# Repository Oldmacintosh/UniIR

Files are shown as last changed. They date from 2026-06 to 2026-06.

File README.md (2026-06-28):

# UniIr — ESP32 Universal Remote

A DIY **universal remote**. An ESP32 captures IR commands from any
remote, stores a command library, and replays them over Bluetooth on request —
and it can run **activity-based automation** on its own: turn your gear on when
there's activity in the room and off again after a period of quiet.

It ships as three parts:

- **Firmware** for the ESP32 (`UniIR.ino`).
- **`UniIr`** — a small Python library that controls the device over its
  Bluetooth/USB serial link (`__init__.py`).
- **A demo GUI** (`demo.py`) that uses the library — capture, replay, organise a
  command library, and configure automation.

It also includes a parametric **3D-printable enclosure** (`UniIR.scad`).

---

## Screenshots

### Circuit / wiring diagram
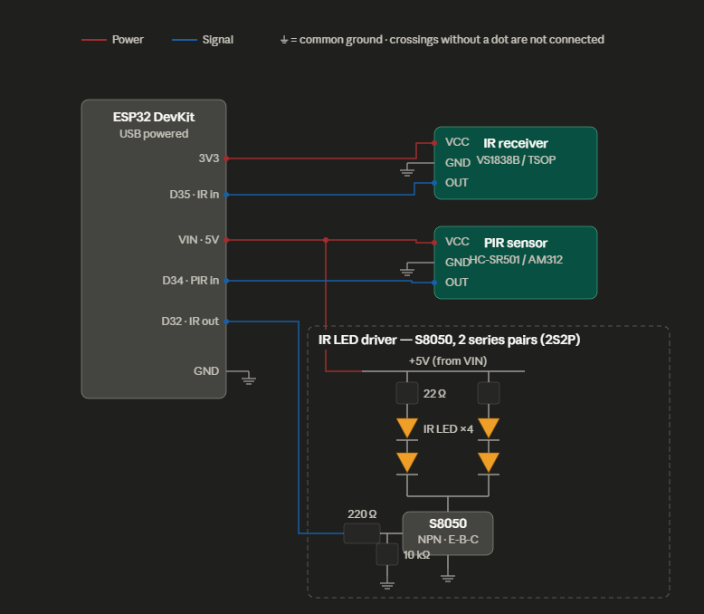
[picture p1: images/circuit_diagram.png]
Circuit diagram


### 3D-printed enclosure
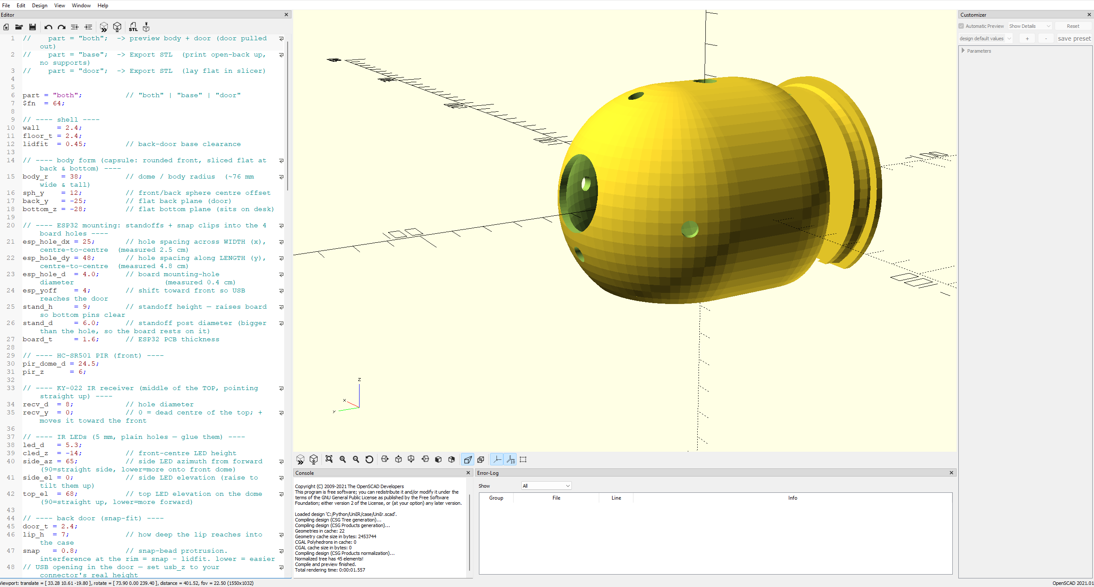
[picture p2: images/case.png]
3D-printed case


### Demo GUI
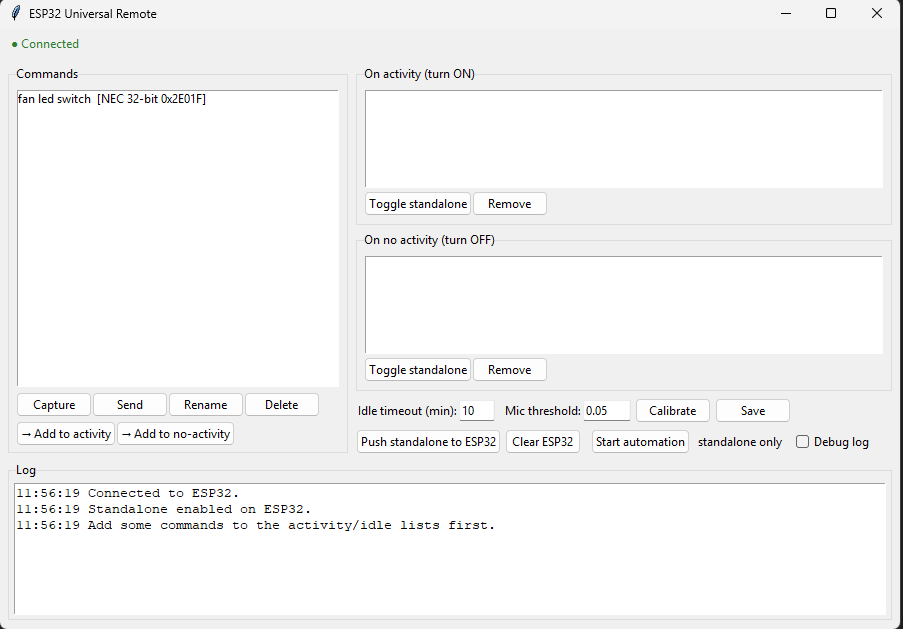
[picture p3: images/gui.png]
Demo GUI


## Table of contents

1. [What it does](#what-it-does)
2. [Project structure](#project-structure)
3. [Hardware](#hardware)
4. [The IR LED driver](#the-ir-led-driver)
5. [3D-printed case](#3d-printed-case)
6. [Firmware](#firmware)
7. [The `UniIr` library](#the-uniir-library)
8. [The demo GUI](#the-demo-gui)
9. [How automation works](#how-automation-works)
10. [macOS Bluetooth notes & troubleshooting](#macos-bluetooth-notes--troubleshooting)
11. [Serial protocol reference](#serial-protocol-reference)

---

## What it does

- **Capture** IR commands from any remote — ordinary remotes (NEC, Sony, RC5,
  etc.), **stateful air-conditioner** remotes (the whole state frame is captured
  and replayed verbatim, so there's no model-lockup risk), and unknown signals
  as **raw** timing.
- **Replay** any stored command on demand.
- **Activity automation** — fuse keyboard, mouse, microphone loudness and a PIR
  motion sensor into a single "active / idle" signal. When activity resumes it
  fires your *on* commands; after a configurable idle timeout it fires your *off*
  commands.
- **Standalone mode** — the ESP32 stores a copy of the automation and keeps
  running it even when the PC is asleep or the app is closed.
- **Self-healing connection** — the library auto-reconnects, verifies the link
  with a handshake, and survives the device resetting (handled carefully because
  macOS Bluetooth serial is fussy about stale links).

---

## Project structure

```
UniIr/
├── __init__.py            # the UniIr library (device client + automation runner)
├── demo.py                # tkinter demo GUI built on the library
├── UniIR.ino              # ESP32 firmware (Arduino)
├── case/                  # parametric enclosure (OpenSCAD)
├── images/                
└── README.md
```

---

## Hardware

### Bill of materials

| Qty | Part | Notes |
|----:|---|---|
| 1 | ESP32 DevKit (30-pin DOIT / WROOM-32) | has built-in Classic Bluetooth |
| 1 | KY-022 IR receiver module | the "eye" that captures remotes |
| 1 | HC-SR501 PIR motion sensor | the big white dome |
| 1 | S8050 NPN transistor | switches the IR LEDs (TO-92) |
| 4 | IR LED, 940 nm, 5 mm | the IR "blasters" |
| 2 | 22 Ω resistor, ¼ W | one per LED branch |
| 1 | 220 Ω resistor, ¼ W | transistor base |
| 1 | 10 kΩ resistor, ¼ W | base pull-down |
| 1 | USB cable + 5 V supply | powers everything |
| — | jumper wires, 3D-printed case | — |

### Pin connections

| ESP32 pin | Connects to | Purpose |
|---|---|---|
| **GPIO35** (D35) | KY-022 **S** (signal out) | IR receive (input-only pin) |
| **GPIO34** (D34) | HC-SR501 **OUT** | PIR motion (input-only pin) |
| **GPIO32** (D32) | 220 Ω → S8050 **base** | IR transmit |
| **3V3** | KY-022 **+ (VCC)** | receiver power |
| **VIN (5V)** | HC-SR501 **VCC**, LED driver **+** | from USB |
| **GND** | all GND, S8050 **emitter**, 10 kΩ | common ground |

> GPIO34 and GPIO35 are **input-only** pins — perfect for the two sensors, and
> they can't accidentally be driven as outputs.

Everything is powered from the ESP32's USB connector; the 5 V for the PIR and the
LED array is taken from the **VIN** pin.

---

## The IR LED driver

A GPIO pin can only source a few milliamps — nowhere near enough to drive IR LEDs
to useful range. So the four LEDs are driven by an **S8050 transistor** in a
**2S2P** arrangement (two parallel branches, each two LEDs in series):

```
              +5V (VIN)
                │
        ┌───────┴───────┐
       22Ω             22Ω
        │               │
       LED             LED
        │               │
       LED             LED
        │               │
        └───────┬───────┘
                │ (collector)
            [ S8050 ]  ── base ── 220Ω ── GPIO32
                │ (emitter)        │
               GND              10kΩ → GND
```

- Each 22 Ω resistor sets ~85–100 mA per branch (~200 mA total).
- The 220 Ω feeds the base; the 10 kΩ holds the transistor off at boot.
- **S8050 pinout is E–B–C** (emitter, base, collector) with the flat face toward
  you — note it's the *reverse* of a BC547.

The firmware only pulses the LEDs during a transmit burst, so the resistors stay
cool. This is the difference between "works only if you aim it" and blasting IR
across a room.

---

## 3D-printed case

`UniIR.scad` is a **parametric** enclosure: a domed front, a flat removable
**snap-fit back door**, and a flat bottom so it sits on a desk. All the four IR
LEDs poke out of the dome (front-centre, left, right and top) for wide coverage,
the PIR dome sits on the front, and the IR receiver looks out the **top centre**.
The ESP32 clips onto four standoffs through its mounting holes.

### Printing it

1. Install [OpenSCAD](https://openscad.org).
2. Open `UniIR.scad`. Every dimension is a variable at the top — set them
   to match your parts (board size, mounting-hole spacing/diameter, etc.).
3. Set `part = "base";`, press **F6** (render), then **File → Export → STL**.
4. Set `part = "door";`, render again, export the door.
5. Slice and print — body open-side up, door laid flat. No supports needed.

Or from the command line:

```bash
openscad -o base.stl -D 'part="base"' ir_hub_case.scad
openscad -o door.stl -D 'part="door"' ir_hub_case.scad
```

**Tunable parameters worth checking first:** `esp_hole_dx` / `esp_hole_dy` /
`esp_hole_d` (your board's mounting holes), `stand_h` (standoff height — must
clear your bottom pins/connectors), `usb_z` (USB connector height), and `snap`
(back-door snap tightness). Set the HC-SR501's two trim pots **before** closing
the case — they end up facing inward.

---

## Firmware

### Toolchain

- [Arduino IDE](https://www.arduino.cc/en/software) with the **ESP32 board
  package** installed (Boards Manager → "esp32" by Espressif).
- Library: **IRremoteESP8266** (Library Manager).
- `BluetoothSerial` ships with the ESP32 core.

### Flashing

1. Open `UniIr.ino` in the Arduino IDE.
2. Select your board (e.g. "DOIT ESP32 DEVKIT V1") and the right serial port.
3. Upload. Open the Serial Monitor at **115200** to watch debug output.

The ESP32 advertises over Bluetooth as **`uniir`**. Pair it from your computer's
Bluetooth settings. On macOS it then appears as the serial device
**`/dev/cu.uniir`**; on Windows it's assigned a COM port.

---

## The `UniIr` library

### Install

```bash
pip install pyserial                       # required
pip install pynput sounddevice numpy       # only needed to RUN automation
```

### Quick start

```python
from UniIr import UniIr            # the device client class

remote = UniIr("/dev/cu.uniir",       # or "COM$" on Windows
            on_status=lambda up: print("connected" if up else "disconnected"),
            on_log=print)

# Capture a button — press the remote when your own UI prompts the user
cmd = remote.capture()                # -> a command dict, or None on timeout
if cmd:
    remote.send(cmd)                  # replay it (blocks until the ESP32 confirms)

# Stream motion events
remote.pir_handler = lambda line: print("motion!" if line == "PIR 1" else "still")

remote.close()
```

The connection is **managed for you**: constructing `UniIr(...)` starts
background threads that open the port, verify it with a handshake, watch a
heartbeat, and reconnect automatically. `remote.connected` is `True` only after a
verified link.

### API reference

**`UniIr(port, baud=115200, on_status=None, on_log=None, auto_connect=True)`**

| Method | Description |
|---|---|
| `capture(timeout=25)` | Capture the next IR signal → command dict or `None` |
| `send(cmd)` | Replay a command, blocking until confirmed → `bool` |
| `send_async(cmd)` | Fire a code/state command without waiting (for automation) |
| `provision(activity_specs, idle_specs, timeout_sec)` | Store standalone automation on the ESP32 → `(ok, where)` |
| `set_standalone(enabled)` | Turn the ESP32's standalone mode on/off |
| `clear_standalone()` | Erase standalone commands from the ESP32 |
| `ping(timeout=3)` | `True` if the device answers |
| `close()` | Stop threads and release the port |

| Attribute | Description |
|---|---|
| `connected` | `True` after a verified handshake |
| `pir_handler` | Set to `f(line)` to receive `"PIR 1"` / `"PIR 0"` motion lines |
| `on_status`, `on_log` | Callbacks (also settable in the constructor) |

### Command data model

A command is a plain `dict`, one of three shapes:

```python
{"type": "code",  "proto": 3, "name": "TV_power", "bits": 32, "value": "20df10ef"}
{"type": "state", "proto": 18, "name": "AC_cool", "nbytes": 3, "bytes": ["a1","b2","c3"]}
{"type": "raw",   "name": "RAW", "data": [9000, 4500, 560, 560, ...]}
```

Helper functions: `describe(cmd)` (human-readable string), `to_spec(cmd)`
(encode for the ESP32; raises for raw), `is_storable(cmd)` (can it run
standalone?).

### Storage helpers

```python
from UniIr import load_data, save_data

data = load_data()                 # -> {"commands": {...}, "automation": {...}}
data["commands"]["tv_power"] = cmd
save_data(data)                    # writes commands.json
```

### Command-line connectivity test

```bash
python -m UniIr            # if installed as a package
# or, from inside the folder:
python __init__.py --port /dev/cu.uniir
```

---

## The demo GUI

`demo.py` is a tkinter app that exercises the whole library. Run it:

```bash
python -m UniIr.demo                 # from the parent folder (recommended)
# or, from inside the UniIr folder:
python demo.py --port /dev/cu.uniir
```

On macOS the default port is `/dev/cu.uniir`, so you can usually omit `--port`.

### What it does

- **Command library** — capture, send, rename and delete IR commands; everything
  is saved to `commands.json`.
- **Automation lists** — add commands to an **On activity** list (fired when
  activity resumes) and an **On no activity** list (fired after the idle
  timeout). Mark commands "standalone" to also store them on the ESP32.
- **Settings** — idle timeout (minutes), microphone threshold, and a
  **Calibrate** button that measures ambient noise and sets a sensible threshold.
- **Push standalone to ESP32 / Clear ESP32** — provision or wipe the device's
  own copy of the automation.
- **Start / Stop automation** and a **Debug log** toggle (see below).
- **Connection status** — a live ● Connected / ● Disconnected indicator and a
  timestamped log.

### macOS permissions

To *run* automation, the OS must allow the Python process to watch input and the
mic:

- **System Settings → Privacy & Security → Microphone** → allow Python/Terminal.
- **System Settings → Privacy & Security → Input Monitoring** → allow
  Python/Terminal.

---

## How automation works

The idea is simple: **activity = devices on, sustained quiet = devices off.**

- The PC runner fuses four signals — **keyboard**, **mouse**, **microphone
  loudness**, and **PIR motion** from the ESP32. Any of them counts as activity.
- When automation starts it **assumes the devices are already on** and begins the
  idle countdown immediately.
- When activity resumes after being idle, it fires the **On activity** commands.
- After `timeout` seconds with no activity from any source, it fires the **On no
  activity** commands.

### Persisted on/off state

Automation has a single saved intent (`enabled` in `commands.json`):

- **First ever launch** → on by default; it starts as soon as the device
  connects.
- After that, the stored state is used and **synced to the ESP32** on every
  connect.
- **Disconnecting stops automation** (it needs the device), and it can only be
  enabled while connected. On reconnect it resumes to the stored state.

### Standalone mode

If you "push standalone to ESP32", the device keeps a copy of your *activity* and
*idle* command lists plus the timeout. When the PC's heartbeat stops (app closed,
laptop asleep), the ESP32 takes over using the PIR sensor alone — so the room
automation keeps working with the computer off.

### Debug mode

Tick **Debug log** to see exactly what's keeping the system awake — useful for
tuning the timeout. With it on, the log shows (tagged `[debug]`):

- `timer reset by keyboard / mouse / sound / motion` every time activity restarts
  the countdown (high-rate sources throttled so they don't flood the log),
- `quiet for Ns — off in Ms` every few seconds while devices are on,
- each command fired, by name, and PIR clear events.

If your gear keeps staying on, debug usually reveals the mic threshold is too low
(catching background noise) or the PIR is re-triggering.

---

## macOS Bluetooth notes & troubleshooting

macOS Bluetooth serial (SPP) is more finicky than Windows. The firmware and
library work around the common issues:

- **"Connected" but nothing happens.** macOS can open a stale port that carries
  no data. The library only reports *Connected* after a **PING/PONG handshake**,
  so a dead link shows as Disconnected and keeps retrying.
- **Won't reconnect after the ESP32 resets without re-pairing.** macOS often
  doesn't tear down the old session. The firmware now **drops its Bluetooth
  client** when the PC's heartbeat stops (~12 s), forcing a fresh session so the
  app reconnects on its own — no re-pair needed.
- **Reconnect detection.** The ESP32 answers each heartbeat with `HBOK`; if the
  library hears nothing for 12 s it declares the link dead and reconnects.

If it still won't reconnect, remove "uniir" in **Bluetooth settings** and pair it
again. On Windows none of this applies — just pass the right `--port COMx`.

---

## Serial protocol reference

All lines are newline-terminated ASCII at 115200 baud.

| Direction | Line | Meaning |
|---|---|---|
| → | `PING` / `HB` | liveness probe / heartbeat |
| ← | `PONG` / `HBOK` | replies |
| → | `CAP` | capture the next IR signal |
| ← | `CODE <proto> <name> <bits> <hex>` | captured a normal remote |
| ← | `STATE <proto> <name> <nbytes> <bytes…>` | captured a stateful (AC) remote |
| ← | `RAW <len> <µs…>` | captured an unknown signal |
| → | `SEND CODE …` / `SEND STATE …` | replay a command |
| → | `LOADRAW <n>` → `D <values…>` → `FIRE` | replay a raw command |
| → | `AUTOCFG <sec>` / `AUTOACT <spec>` / `AUTOIDLE <spec>` / `AUTOSAVE` | provision standalone |
| → | `AUTOEN 1\|0` / `AUTOCLEAR` | enable/disable / wipe standalone |
| ← | `PIR 1` / `PIR 0` | async motion start / stop |
| ← | `ACK` / `SENT` / `TIMEOUT` | acknowledgements |

---

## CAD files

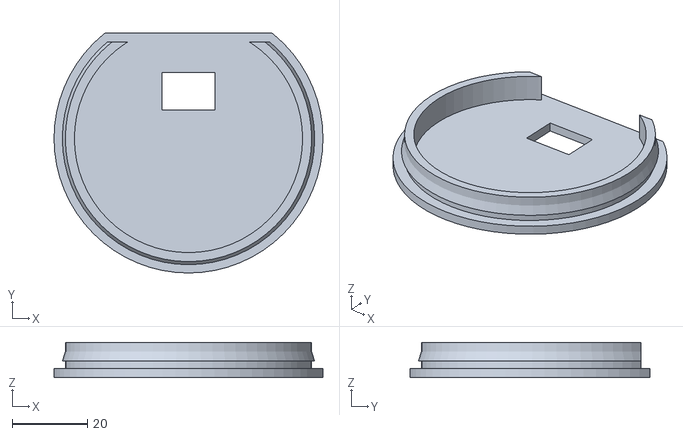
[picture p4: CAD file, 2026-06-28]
case/door.stl
71.4 x 63.7 x 9.40

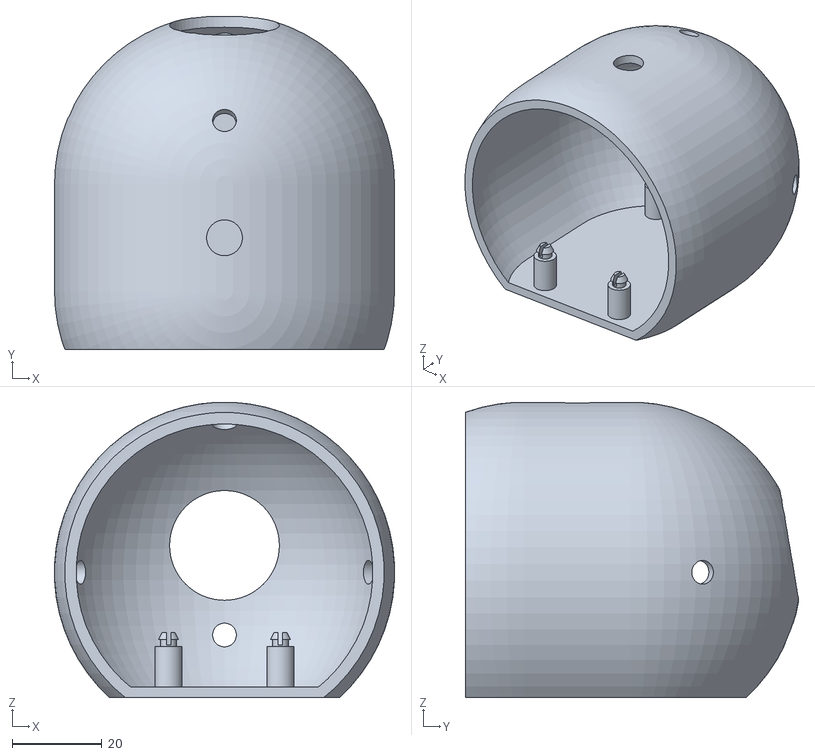
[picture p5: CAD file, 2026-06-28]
case/base.stl
75.9 x 74.5 x 66.0

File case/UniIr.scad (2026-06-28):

//    part = "both";  -> preview body + door (door pulled out)
//    part = "base";  -> Export STL  (print open-back up, no supports)
//    part = "door";  -> Export STL  (lay flat in slicer)


part = "both";          // "both" | "base" | "door"
$fn  = 64;

// ---- shell ----
wall    = 2.4;
floor_t = 2.4;
lidfit  = 0.45;         // back-door base clearance

// ---- body form (capsule: rounded front, sliced flat at back & bottom) ----
body_r   = 38;          // dome / body radius  (~76 mm wide & tall)
sph_y    = 12;          // front/back sphere centre offset
back_y   = -25;         // flat back plane (door)
bottom_z = -28;         // flat bottom plane (sits on desk)

// ---- ESP32 mounting: standoffs + snap clips into the 4 board holes ----
esp_hole_dx = 25;       // hole spacing across WIDTH (x), centre-to-centre  (measured 2.5 cm)
esp_hole_dy = 48;       // hole spacing along LENGTH (y), centre-to-centre  (measured 4.8 cm)
esp_hole_d  = 4.0;      // board mounting-hole diameter                     (measured 0.4 cm)
esp_yoff    = 4;        // shift toward front so USB reaches the door
stand_h     = 9;        // standoff height — raises board so bottom pins clear
stand_d     = 6.0;      // standoff post diameter (bigger than the hole, so the board rests on it)
board_t     = 1.6;      // ESP32 PCB thickness

// ---- HC-SR501 PIR (front) ----
pir_dome_d = 24.5;
pir_z      = 6;

// ---- KY-022 IR receiver (middle of the TOP, pointing straight up) ----
recv_d  = 8;            // hole diameter
recv_y  = 0;            // 0 = dead centre of the top; + moves it toward the front

// ---- IR LEDs (5 mm, plain holes — glue them) ----
led_d   = 5.3;
cled_z  = -14;          // front-centre LED height
side_az = 65;           // side LED azimuth from forward (90=straight side, lower=more onto front dome)
side_el = 0;            // side LED elevation (raise to tilt them up)
top_el  = 68;           // top LED elevation on the dome (90=straight up, lower=more forward)

// ---- back door (snap-fit) ----
door_t = 2.4;
lip_h  = 7;             // how deep the lip reaches into the case
snap   = 0.8;           // snap-bead protrusion. interference at the rim = snap - lidfit. lower = easier
// USB opening in the door — set usb_z to your connector's real height
usb_w  = 14;
usb_h  = 10;
usb_z  = -12.5;         // centre height of the USB connector (board is raised on the standoffs)

// ---- derived ----
back_cy = -sph_y;
r_back  = sqrt(body_r*body_r - (back_y-back_cy)*(back_y-back_cy));
r_in    = sqrt((body_r-wall)*(body_r-wall) - (back_y-back_cy)*(back_y-back_cy));
floor_z = bottom_z + floor_t;

// =====================================================================
//  helpers
// =====================================================================
// a +Y hole (the part faces outward along +Y); place at desired x/z
module led_y(dd) { translate([0,-5,0]) rotate([-90,0,0]) cylinder(h=70, d=dd); }

// place a child (modelled along +Y outward) on the FRONT dome surface
module place_dome(el, az) {
    translate([0, sph_y, 0]) rotate([0,0,az]) rotate([el,0,0])
        translate([0, body_r, 0]) children();
}

// snap-clip post: standoff + split peg + barb that clicks into a board hole
module clip_post() {
    peg_d  = esp_hole_d - 0.4;     // peg passes through the hole
    barb_d = esp_hole_d + 0.5;     // smaller barb so it snaps in easily (was +1.0)
    cylinder(d=stand_d, h=stand_h);                       // standoff (board rests on top)
    difference() {
        union() {
            translate([0,0,stand_h]) cylinder(d=peg_d, h=board_t);             // peg through hole
            translate([0,0,stand_h+board_t])
                cylinder(d1=barb_d, d2=peg_d-0.8, h=1.6);                       // retaining barb (tapered)
        }
        translate([-0.5, -barb_d, stand_h+0.4]) cube([1.0, 2*barb_d, board_t+2.4]); // flex slot
    }
}

module body_outer() {
    difference() {
        hull() {
            translate([0,  sph_y, 0]) sphere(body_r);
            translate([0, -sph_y, 0]) sphere(body_r);
        }
        translate([-200, back_y-400, -200]) cube([400,400,400]);   // flat back
        translate([-200, -200, bottom_z-400]) cube([400,400,400]); // flat bottom
    }
}

module body_inner() {
    difference() {
        hull() {
            translate([0,  sph_y, 0]) sphere(body_r-wall);
            translate([0, -sph_y, 0]) sphere(body_r-wall);
        }
        translate([-200, -200, floor_z-400]) cube([400,400,400]); // leave a floor
    }
}

module mounts() {
    for (sx=[-1,1]) for (sy=[-1,1])
        translate([sx*esp_hole_dx/2, esp_yoff + sy*esp_hole_dy/2, floor_z]) clip_post();
}

module holes() {
    translate([0,      0, pir_z])  led_y(pir_dome_d);                // PIR dome (front)
    translate([0,      0, cled_z]) led_y(led_d);                     // centre LED (front)
    translate([0, recv_y, -5]) cylinder(h=60, d=recv_d);            // KY-022 receiver (middle of top, +Z)
    place_dome(top_el, 0)        led_y(led_d);                       // top LED (on dome curve)
    place_dome(side_el,  side_az) led_y(led_d);                      // left LED (on dome curve)
    place_dome(side_el, -side_az) led_y(led_d);                      // right LED (on dome curve)
}

module base() {
    difference() {
        union() {
            difference() { body_outer(); body_inner(); }   // hollow shell, open back
            mounts();
        }
        holes();
    }
}

module door() {
    lip_r  = r_in - lidfit;        // lip slides into the opening with clearance
    bead_r = lip_r + snap;         // bead is larger than the rim -> it clicks past and is held
    ramp   = 2.5;
    bead_y = 2.0;                  // bead sits just inside the rim
    difference() {
        union() {
            // outer plate — covers the whole flat back, clipped to the flat BOTTOM
            intersection() {
                translate([0, back_y, 0]) rotate([90,0,0]) cylinder(h=door_t, r=r_back);
                translate([-200,-200,bottom_z]) cube([400,400,400]);
            }
            // lip + snap bead — clipped to the cavity FLOOR so it can't jam on the floor
            intersection() {
                union() {
                    // hollow lip ring
                    difference() {
                        translate([0, back_y+lip_h, 0]) rotate([90,0,0]) cylinder(h=lip_h, r=lip_r);
                        translate([0, back_y+lip_h+0.1, 0]) rotate([90,0,0]) cylinder(h=lip_h+0.2, r=lip_r-2.4);
                    }
                    // snap bead: ramp on the tip side, catch shoulder toward the plate
                    difference() {
                        translate([0, back_y+bead_y+ramp, 0]) rotate([90,0,0]) cylinder(h=ramp, r1=lip_r, r2=bead_r);
                        translate([0, back_y+bead_y+ramp+0.1, 0]) rotate([90,0,0]) cylinder(h=ramp+0.2, r=lip_r-2.4);
                    }
                }
                translate([-200,-200,floor_z]) cube([400,400,400]);
            }
        }
        // USB opening through the plate at the connector height
        translate([-usb_w/2, back_y-door_t-2, usb_z-usb_h/2]) cube([usb_w, door_t+lip_h+4, usb_h]);
    }
}

// ---- layout / export ----
if (part == "base" || part == "both") base();
if (part == "both") translate([0, -20, 0]) door();
if (part == "door") rotate([90,0,0]) door();

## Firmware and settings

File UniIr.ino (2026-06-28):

/*
 * Protocol over Bluetooth (lines, '\n'):
 *   PING -> PONG          HB -> (silent, resets controller timer)
 *   CAP  -> CAPTURING / CODE.. / STATE.. / RAW.. / TIMEOUT
 *   SEND CODE <proto> <bits> <valHex>     -> SENT
 *   SEND STATE <proto> <nbytes> <b..>     -> SENT
 *   LOADRAW <len> / D <us..> / FIRE       -> ACK / ACK / SENT   (manual raw)
 *   LEN? -> LEN <n>
 *   AUTOCFG <timeoutSec>                  -> ACK   (clear lists, set timeout)
 *   AUTOACT  <spec>                       -> ACK   (append activity command)
 *   AUTOIDLE <spec>                       -> ACK   (append idle command)
 *   AUTOSAVE -> ACK     AUTOCLEAR -> ACK     AUTOSHOW -> CFG.. / ACT.. / IDLE..
 *   (async) PIR 1 / PIR 0
 * <spec> = "CODE <proto> <bits> <valHex>" or "STATE <proto> <nbytes> <b..>".
 */

#include <Arduino.h>
#include "BluetoothSerial.h"
#include <Preferences.h>
#include <IRremoteESP8266.h>
#include <IRsend.h>
#include <IRrecv.h>
#include <IRutils.h>

#if !defined(CONFIG_BT_ENABLED) || !defined(CONFIG_BLUEDROID_ENABLED)
#error Bluetooth is not enabled. Select a classic ESP32 (WROOM) board.
#endif
#if !defined(CONFIG_BT_SPP_ENABLED)
#error Serial Bluetooth (SPP) not available. Select a classic ESP32 (WROOM) board.
#endif

const uint16_t kRecvPin = 35;
const uint16_t kSendPin = 32;
const uint16_t kPirPin  = 34;

const uint16_t kCaptureBufferSize = 1024;
const uint8_t  kTimeout           = 50;
const uint16_t kMinUnknownSize    = 12;
const uint8_t  kFrequency         = 38;
const unsigned long CAPTURE_TIMEOUT_MS    = 20000UL;
const unsigned long CONTROLLER_TIMEOUT_MS = 12000UL;

BluetoothSerial SerialBT;
IRrecv  irrecv(kRecvPin, kCaptureBufferSize, kTimeout, true);
IRsend  irsend(kSendPin);
Preferences prefs;
decode_results results;

// ---- autonomous command lists (persisted in NVS) ----------------------
#define MAX_ACT  4
#define MAX_IDLE 4
String   actList[MAX_ACT];
String   idleList[MAX_IDLE];
int      nAct = 0, nIdle = 0;
uint32_t autoTimeoutMs = 600000UL;
bool     autoEnabled   = false;       // standalone allowed? toggled from the app, persisted

// ---- runtime state -----------------------------------------------------
bool          pirState   = false;
unsigned long lastMotion = 0;
bool          autoOn     = false;     // assumed device state while standalone
unsigned long lastHB     = 0;
bool          hbSeen      = false;
bool          wasPresent  = true;     // for present->absent edge detection

// ---- raw manual-send buffer -------------------------------------------
#define RAW_MAX 600
uint16_t rawBuf[RAW_MAX];
uint16_t rawIdx = 0;

// ---- line reader -------------------------------------------------------
char     lineBuf[300];
uint16_t linePos = 0;

bool readLineBT() {
  while (SerialBT.available()) {
    char c = SerialBT.read();
    if (c == '\r') continue;
    if (c == '\n') { lineBuf[linePos] = '\0'; linePos = 0; return true; }
    if (linePos < sizeof(lineBuf) - 1) lineBuf[linePos++] = c;
    else linePos = 0;
  }
  return false;
}

long ti(char *s) { return s ? atol(s) : 0; }

// ---- NVS ---------------------------------------------------------------
void loadConfig() {
  prefs.begin("irauto", true);
  autoTimeoutMs = (uint32_t) prefs.getUInt("to", 600) * 1000UL;
  autoEnabled = prefs.getBool("en", false);
  nAct  = prefs.getInt("na", 0); if (nAct  > MAX_ACT)  nAct  = MAX_ACT;
  nIdle = prefs.getInt("ni", 0); if (nIdle > MAX_IDLE) nIdle = MAX_IDLE;
  char k[6];
  for (int i = 0; i < nAct;  i++) { snprintf(k, sizeof(k), "a%d", i); actList[i]  = prefs.getString(k, ""); }
  for (int i = 0; i < nIdle; i++) { snprintf(k, sizeof(k), "i%d", i); idleList[i] = prefs.getString(k, ""); }
  prefs.end();
}

void saveConfig() {
  prefs.begin("irauto", false);
  prefs.clear();
  prefs.putUInt("to", autoTimeoutMs / 1000UL);
  prefs.putBool("en", autoEnabled);
  prefs.putInt("na", nAct);
  prefs.putInt("ni", nIdle);
  char k[6];
  for (int i = 0; i < nAct;  i++) { snprintf(k, sizeof(k), "a%d", i); prefs.putString(k, actList[i]); }
  for (int i = 0; i < nIdle; i++) { snprintf(k, sizeof(k), "i%d", i); prefs.putString(k, idleList[i]); }
  prefs.end();
}

// ---- IR send from a text spec -----------------------------------------
void fireSpec(char *spec) {
  char *t = strtok(spec, " ");
  if (!t) return;
  if (!strcmp(t, "CODE")) {
    decode_type_t p   = (decode_type_t) ti(strtok(NULL, " "));
    uint16_t      bit = ti(strtok(NULL, " "));
    char         *vh  = strtok(NULL, " ");
    uint64_t      val = vh ? strtoull(vh, NULL, 16) : 0;
    irsend.send(p, val, bit);
  } else if (!strcmp(t, "STATE")) {
    decode_type_t p  = (decode_type_t) ti(strtok(NULL, " "));
    uint16_t      nb = ti(strtok(NULL, " "));
    uint8_t st[64]; uint16_t n = 0; char *b;
    while (n < nb && n < 64 && (b = strtok(NULL, " "))) st[n++] = (uint8_t) strtoul(b, NULL, 16);
    irsend.send(p, st, n);
  }
}

void fireList(String *list, int n, const char *tag) {
  Serial.print(F("AUTO: firing ")); Serial.print(tag);
  Serial.print(F(" (")); Serial.print(n); Serial.println(F(" cmd)"));
  char buf[280];
  for (int i = 0; i < n; i++) {
    list[i].toCharArray(buf, sizeof(buf));
    fireSpec(buf);
    delay(60);
  }
}

// ---- capture -----------------------------------------------------------
void doCapture() {
  SerialBT.println(F("CAPTURING"));
  irrecv.resume();
  unsigned long start = millis();
  while (millis() - start < CAPTURE_TIMEOUT_MS) {
    if (!irrecv.decode(&results)) { delay(1); continue; }
    decode_type_t proto = results.decode_type;
    if (proto == UNKNOWN) {
      uint16_t len  = getCorrectedRawLength(&results);
      uint16_t *raw = resultToRawArray(&results);
      SerialBT.print(F("RAW ")); SerialBT.print(len);
      for (uint16_t i = 0; i < len; i++) { SerialBT.print(' '); SerialBT.print(raw[i]); }
      SerialBT.println();
      delete[] raw;
    } else if (hasACState(proto)) {
      uint16_t nbytes = results.bits / 8;
      SerialBT.print(F("STATE ")); SerialBT.print((int)proto); SerialBT.print(' ');
      SerialBT.print(typeToString(proto)); SerialBT.print(' '); SerialBT.print(nbytes);
      for (uint16_t i = 0; i < nbytes; i++) {
        SerialBT.print(' ');
        if (results.state[i] < 0x10) SerialBT.print('0');
        SerialBT.print(results.state[i], HEX);
      }
      SerialBT.println();
    } else {
      SerialBT.print(F("CODE ")); SerialBT.print((int)proto); SerialBT.print(' ');
      SerialBT.print(typeToString(proto)); SerialBT.print(' ');
      SerialBT.print(results.bits); SerialBT.print(' ');
      SerialBT.println(uint64ToString(results.value, 16));
    }
    irrecv.resume();
    return;
  }
  SerialBT.println(F("TIMEOUT"));
}

// ---- command dispatch --------------------------------------------------
void handleCommand() {
  if (!strcmp(lineBuf, "PING")) { SerialBT.println(F("PONG")); return; }
  if (!strcmp(lineBuf, "HB"))   { lastHB = millis(); hbSeen = true; SerialBT.println(F("HBOK")); return; }
  if (!strcmp(lineBuf, "CAP"))  { doCapture(); return; }

  if (!strncmp(lineBuf, "SEND ", 5)) { fireSpec(lineBuf + 5); SerialBT.println(F("SENT")); return; }

  if (!strcmp(lineBuf, "LEN?"))        { SerialBT.print(F("LEN ")); SerialBT.println(rawIdx); return; }
  if (!strncmp(lineBuf, "LOADRAW", 7)) { rawIdx = 0; SerialBT.println(F("ACK")); return; }
  if (lineBuf[0] == 'D' && lineBuf[1] == ' ') {
    char *v = strtok(lineBuf + 2, " ");
    while (v) { if (rawIdx < RAW_MAX) rawBuf[rawIdx++] = (uint16_t) atol(v); v = strtok(NULL, " "); }
    SerialBT.println(F("ACK")); return;
  }
  if (!strcmp(lineBuf, "FIRE")) {
    if (rawIdx == 0) { SerialBT.println(F("ERR_EMPTY")); return; }
    irsend.sendRaw(rawBuf, rawIdx, kFrequency);
    SerialBT.println(F("SENT")); return;
  }

  // provisioning
  if (!strncmp(lineBuf, "AUTOCFG ", 8)) {
    autoTimeoutMs = (uint32_t) ti(lineBuf + 8) * 1000UL;
    nAct = 0; nIdle = 0;
    SerialBT.println(F("ACK")); return;
  }
  if (!strncmp(lineBuf, "AUTOACT ", 8)) {
    if (nAct < MAX_ACT) actList[nAct++] = String(lineBuf + 8);
    SerialBT.println(F("ACK")); return;
  }
  if (!strncmp(lineBuf, "AUTOIDLE ", 9)) {
    if (nIdle < MAX_IDLE) idleList[nIdle++] = String(lineBuf + 9);
    SerialBT.println(F("ACK")); return;
  }
  if (!strncmp(lineBuf, "AUTOEN ", 7)) {
    autoEnabled = ti(lineBuf + 7) != 0;
    if (!autoEnabled) autoOn = false;
    saveConfig();
    Serial.print(F("AUTO: standalone ")); Serial.println(autoEnabled ? F("ENABLED") : F("DISABLED"));
    SerialBT.println(F("ACK")); return;
  }
  if (!strcmp(lineBuf, "AUTOSAVE"))  { saveConfig(); SerialBT.println(F("ACK")); return; }
  if (!strcmp(lineBuf, "AUTOCLEAR")) { nAct = 0; nIdle = 0; autoOn = false; saveConfig(); SerialBT.println(F("ACK")); return; }
  if (!strcmp(lineBuf, "AUTOSHOW")) {
    SerialBT.print(F("CFG ")); SerialBT.print(autoTimeoutMs / 1000UL);
    SerialBT.print(' '); SerialBT.print(nAct); SerialBT.print(' '); SerialBT.println(nIdle);
    return;
  }

  SerialBT.println(F("ERR"));
}

// ---- PIR + autonomous --------------------------------------------------
void updatePir() {
  bool m = digitalRead(kPirPin);
  if (m != pirState) {
    pirState = m;
    SerialBT.print(F("PIR ")); SerialBT.println(m ? 1 : 0);
  }
  if (m) lastMotion = millis();
}

void autonomousTick() {
  if (!autoEnabled || (nAct == 0 && nIdle == 0)) return;
  unsigned long now = millis();
  if (!autoOn && pirState) {
    Serial.println(F("AUTO: motion detected"));
    fireList(actList, nAct, "activity");
    autoOn = true;
  } else if (autoOn && (now - lastMotion > autoTimeoutMs)) {
    Serial.println(F("AUTO: idle timeout"));
    fireList(idleList, nIdle, "idle");
    autoOn = false;
  }
}

void setup() {
  Serial.begin(115200);
  pinMode(kPirPin, INPUT);
  SerialBT.begin("UniIr");
  irrecv.setUnknownThreshold(kMinUnknownSize);
  irrecv.enableIRIn();
  irsend.begin();
  loadConfig();
  Serial.print(F("Ready. activity cmds=")); Serial.print(nAct);
  Serial.print(F(" idle cmds=")); Serial.print(nIdle);
  Serial.print(F(" timeout(s)=")); Serial.println(autoTimeoutMs / 1000UL);
  SerialBT.println(F("BOOT"));
}

void loop() {
  updatePir();
  if (readLineBT()) handleCommand();

  bool present = hbSeen && (millis() - lastHB < CONTROLLER_TIMEOUT_MS);

  // present -> absent edge: the PC's heartbeat stopped.
  if (wasPresent && !present) {
    // Force any lingering Bluetooth client off. macOS often won't tear down the
    // old RFCOMM session itself, so the ESP32 must, or the next app launch
    // reconnects onto a dead channel (looks connected, no data) until re-pair.
    if (SerialBT.hasClient()) {
      SerialBT.disconnect();
      Serial.println(F("BT: heartbeat lost, dropped client for a clean reconnect"));
    }
    if (autoEnabled) {
      autoOn = true;
      lastMotion = millis();
      Serial.println(F("AUTO: standalone start - assuming ON, idle countdown"));
    }
  }
  wasPresent = present;

  if (!present) autonomousTick();
}
